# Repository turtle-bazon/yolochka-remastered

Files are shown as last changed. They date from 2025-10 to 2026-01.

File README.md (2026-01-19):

# Yolochka Remastered

Yolochka Remastered is a 36 keys (3x5 + 3 thumbs per hand) row staggered keyboard, inspired by [Aroum's YOLOCHKA](https://github.com/aroum/yolochka). It started as an attempt to turn the original YOLOCHKA into a PCB-based design.

## Images

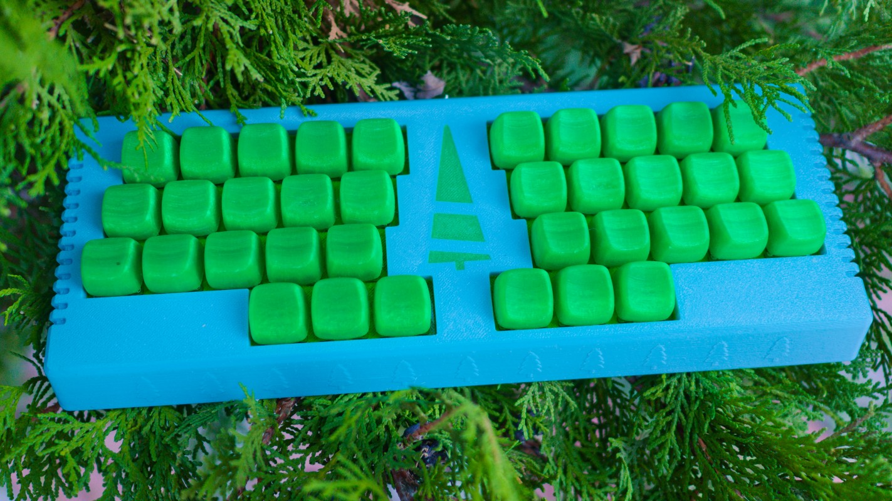
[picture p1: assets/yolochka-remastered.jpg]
yolochka-remastered


## PCB Images

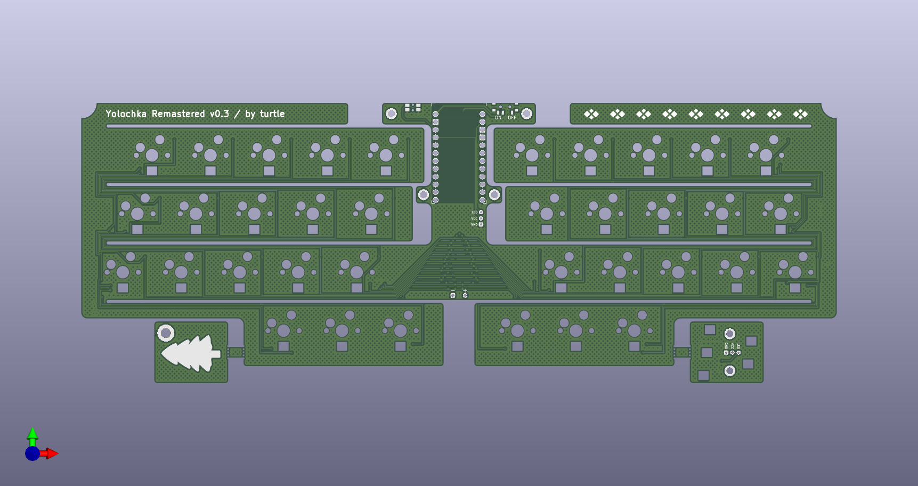
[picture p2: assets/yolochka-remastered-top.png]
yolochka-remastered-top


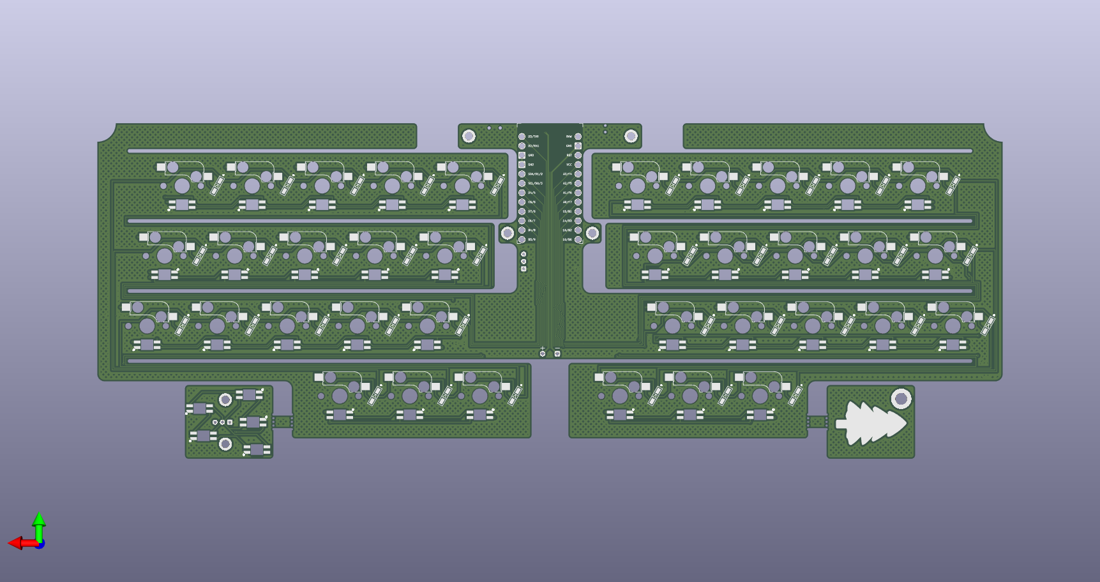
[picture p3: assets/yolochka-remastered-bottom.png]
yolochka-remastered-bottom


## Bill Of Materials

| Item | Quantity | Remarks |
| ---|---| ---|
| NRFproMicro | 1 | [Link](https://aliexpress.com/item/1005007088422530.html) |
| MX Style Mechanical Switch | 36 | Any green themed colors, but works any, see below |
| MX HotSwap Socket | 36 | Any MX Compatible, but green preferred |
| SMD Diode 1n4148 SOD123 | 36 | If you can find green or red is good |
| SK6812MINI-E | 41 | |
| MSK12C02 | 1 | Power switch |
| EVQP7C01K | 1 | Reset switch |
| 14500 li-ion battery | 2 | |
| 24 AWG wire | | Or something similar |
| M2 threaded insert | 11 | 3mm, OD 3.2mm |
| M2x4 Countersunk head | 2 | For led panel |
| M2x10 Countersunk head | 4 | For PCB |
| M2x5 Countersunk head | 7 | For Case |

## Firmware

My zmk repo is available [here](https://github.com/turtle-bazon/zmk-yolochka-remastered)

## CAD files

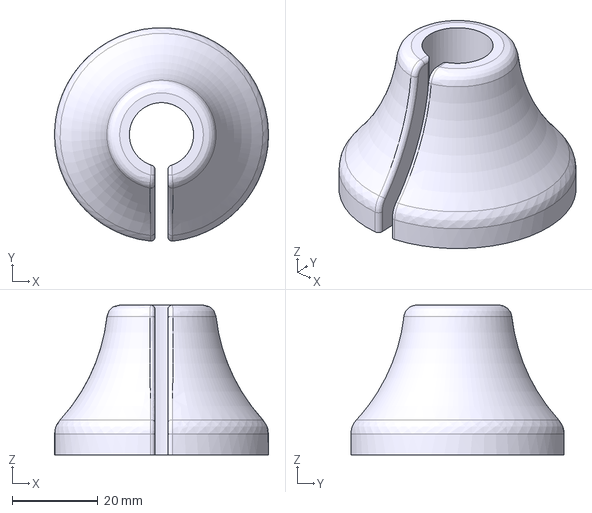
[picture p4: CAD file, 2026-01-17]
case/export/helpers/yolochka-remastered-14500-solder-helper.step
50.0 x 49.8 x 35.0 mm

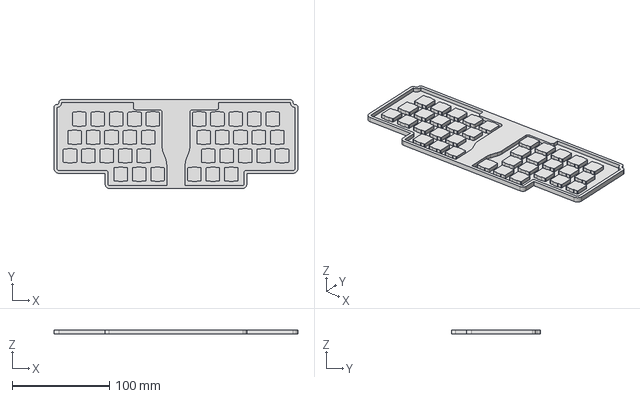
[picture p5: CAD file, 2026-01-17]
case/export/silicone-molds/yolochka-remastered-switchplate-below1.4mm-mold.step
251.5 x 91.5 x 4.60 mm

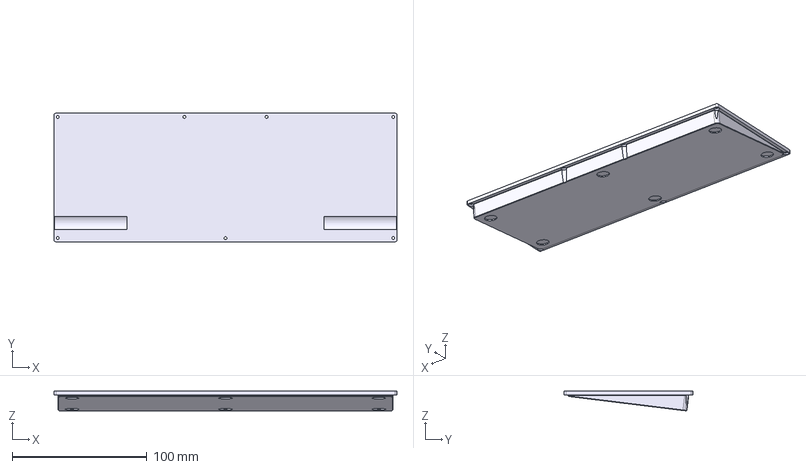
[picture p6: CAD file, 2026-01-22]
case/export/yolochka-remastered-bottom-tented.step
254.5 x 95.5 x 14.7 mm

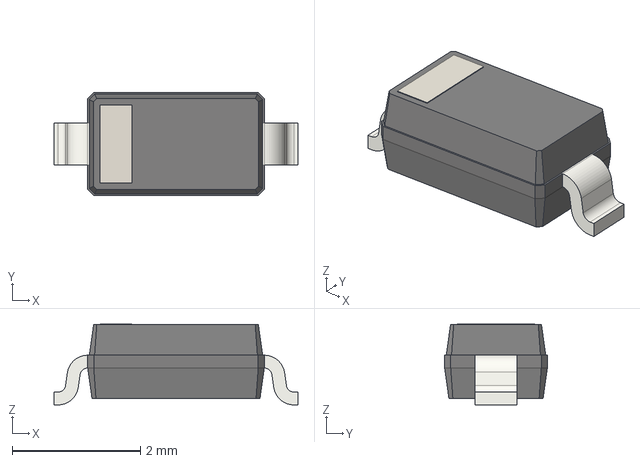
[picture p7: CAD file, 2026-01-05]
pcb/yolochka_lib/3d/D_SOD-123.step
3.80 x 1.60 x 1.26 mm

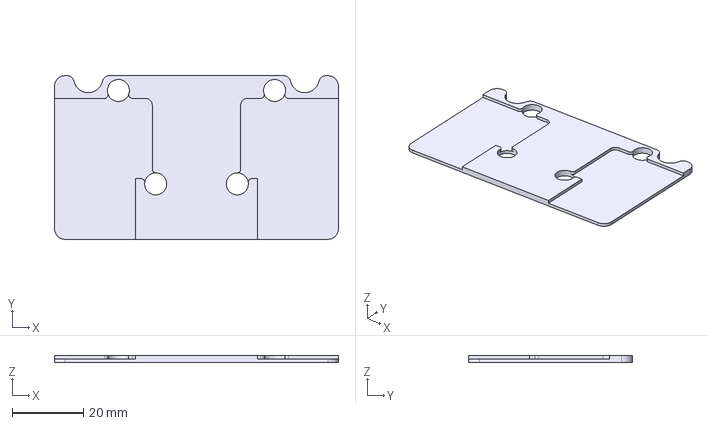
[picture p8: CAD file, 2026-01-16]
case/export/helpers/yolochka-remastered-thread-inserts-helper.step
80.0 x 46.1 x 2.00 mm

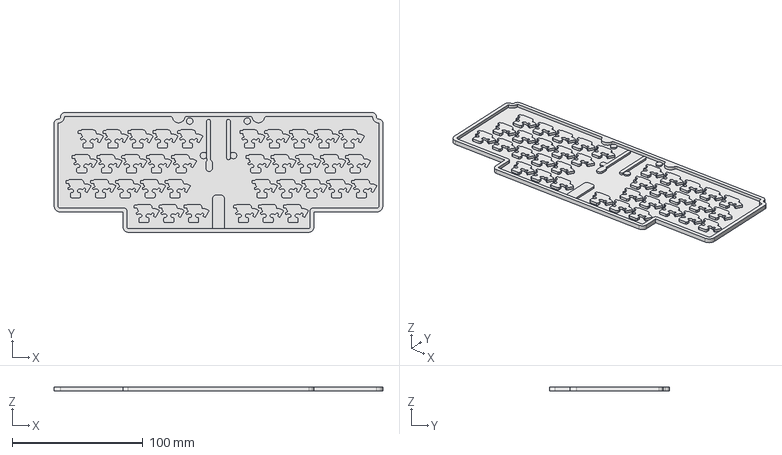
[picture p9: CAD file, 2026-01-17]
case/export/silicone-molds/yolochka-remastered-bottom-fill-mold.step
251.5 x 91.5 x 3.40 mm

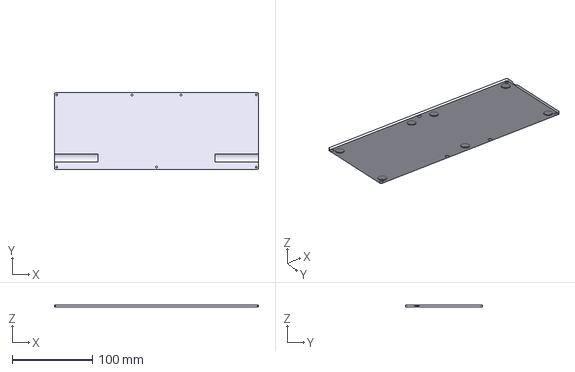
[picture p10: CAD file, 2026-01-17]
case/export/yolochka-remastered-bottom.step
254.5 x 95.5 x 3.00 mm

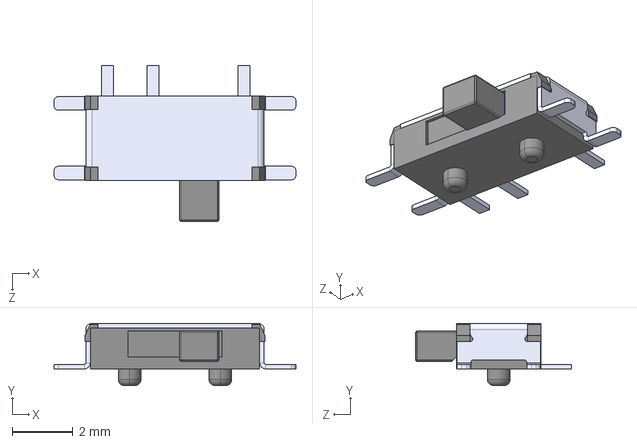
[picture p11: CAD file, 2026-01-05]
pcb/yolochka_lib/3d/MSK12C02.step
8.00 x 2.05 x 5.15 mm

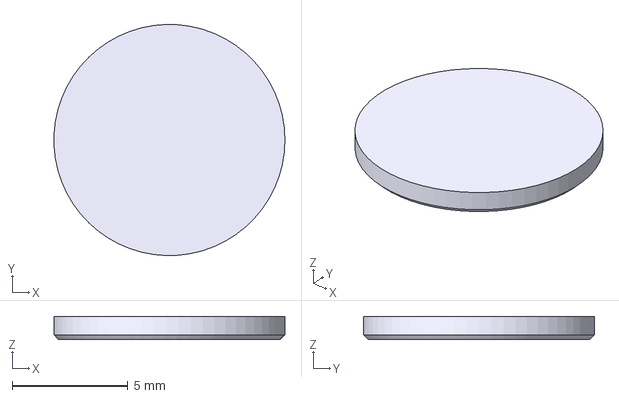
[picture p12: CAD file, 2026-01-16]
case/export/helpers/yolochka-remastered-10mmbumponsupport.step
9.99 x 10.00 x 1.00 mm

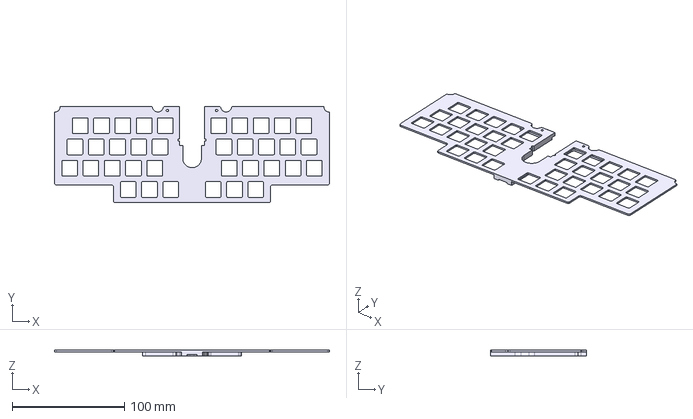
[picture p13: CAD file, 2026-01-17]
case/export/yolochka-remastered-switchplate-1.4mm.step
245.5 x 85.5 x 5.00 mm

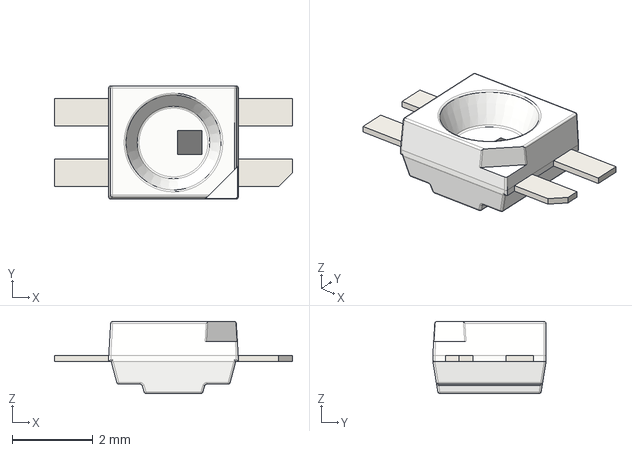
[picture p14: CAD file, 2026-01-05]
pcb/yolochka_lib/3d/LED_SK6812MINI-E.step
5.88 x 2.80 x 1.78 mm

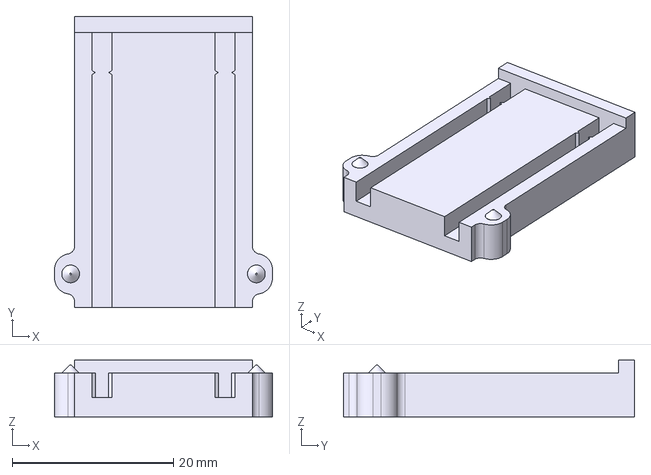
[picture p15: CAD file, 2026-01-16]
case/export/helpers/yolochka-remastered-mcu-headers-soldering-helper.step
27.0 x 36.1 x 7.00 mm

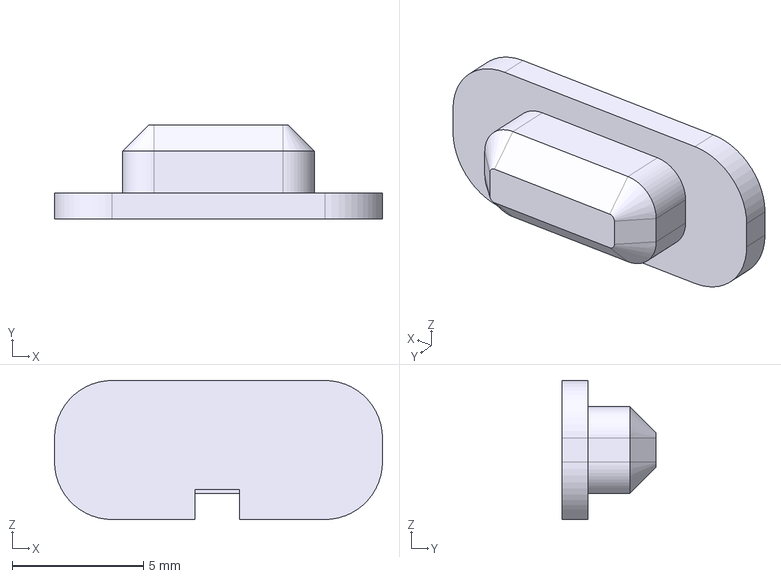
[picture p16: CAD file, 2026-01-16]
case/export/yolochka-remastered-power-switch-pusher.step
12.5 x 3.60 x 5.30 mm

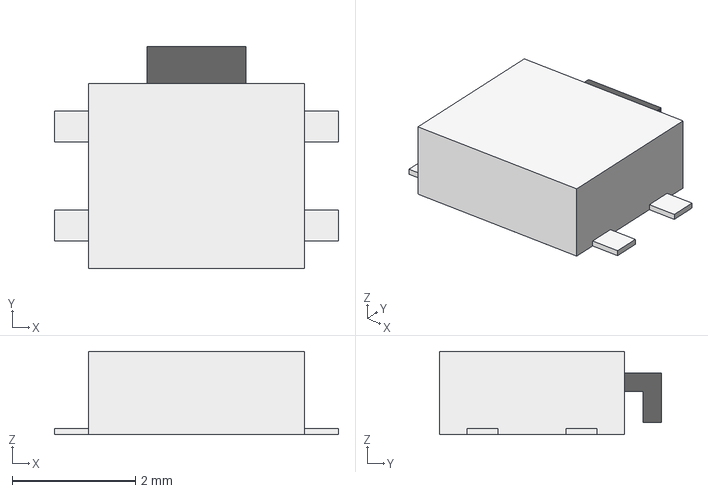
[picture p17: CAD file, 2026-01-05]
pcb/yolochka_lib/3d/turtle-tactile-switch-3x4-body.step
4.60 x 3.60 x 1.35 mm
metal-part
plastic-part

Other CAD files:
case/export/yolochka-remastered-bumpon.step
pcb/yolochka_lib/3d/SuperMini_FlatConnector.step
case/export/yolochka-remastered-top.step
pcb/yolochka_lib/3d/HotswapMX.stp
case/export/yolochka-remastered-bottom-fill.step
case/export/yolochka-remastered-reset-button-pusher.step
case/export/yolochka-remastered-switchplate.step
case/export/yolochka-remastered-top-fill.step

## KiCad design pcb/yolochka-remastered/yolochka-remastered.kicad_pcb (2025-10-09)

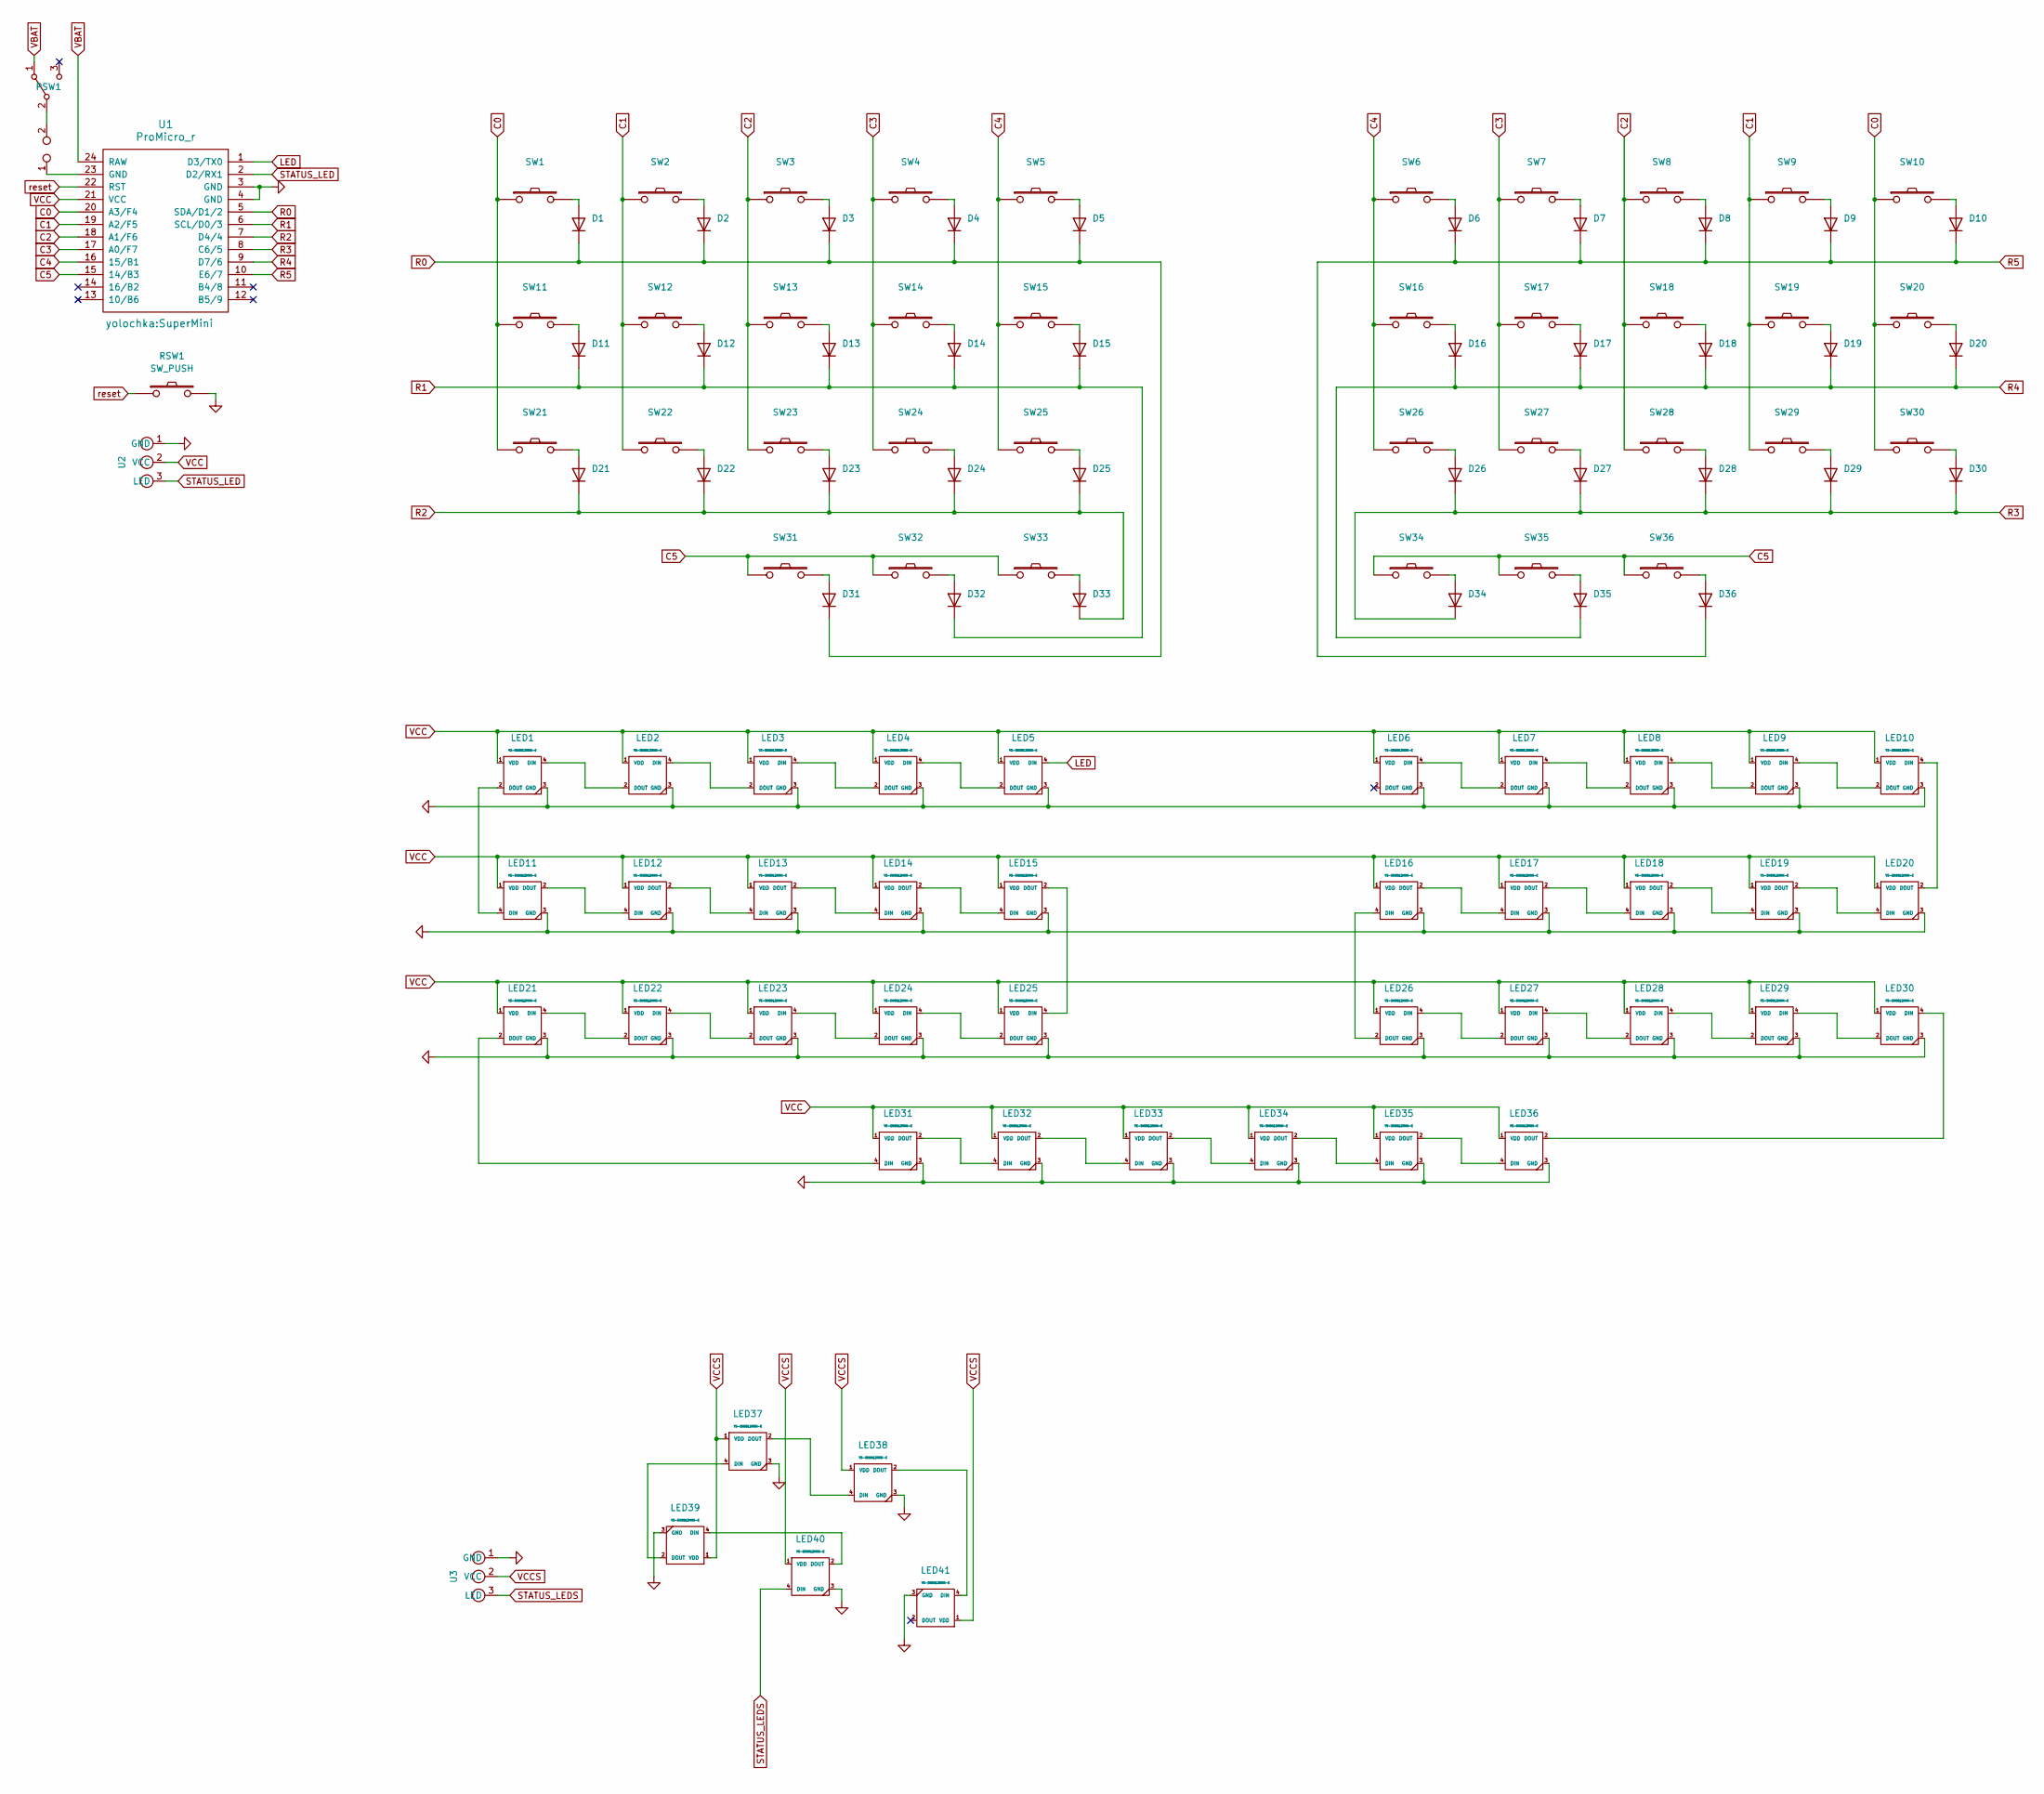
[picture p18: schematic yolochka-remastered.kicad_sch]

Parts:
D1, D2, D3, D4, D5, D6, D7, D8, D9, D10, D11, D12, D13, D14, D15, D16, D17, D18, D19, D20, D21, D22, D23, D24, D25, D26, D27, D28, D29, D30, D31, D32, D33, D34, D35, D36: 1N4148; D3_SMD_single
LED1, LED2, LED3, LED4, LED5, LED6, LED7, LED8, LED9, LED10, LED11, LED12, LED13, LED14, LED15, LED16, LED17, LED18, LED19, LED20, LED21, LED22, LED23, LED24, LED25, LED26, LED27, LED28, LED29, LED30, LED31, LED32, LED33, LED34, LED35, LED36, LED37, LED38, LED39, LED40, LED41: YS-SK6812MINI-E; YS-SK6812MINI-E_single
PSW1: SW_SPDT; MSK-12C02
RSW1: SW_PUSH; SW_EVQP7C01K
SW1, SW2, SW3, SW4, SW5, SW6, SW7, SW8, SW9, SW10, SW11, SW12, SW13, SW14, SW15, SW16, SW17, SW18, SW19, SW20, SW21, SW22, SW23, SW24, SW25, SW26, SW27, SW28, SW29, SW30, SW31, SW32, SW33, SW34, SW35, SW36: SW_PUSH; MX-single
TP1: TestPoint_2Pole; battery_conn_duplex
U1: ProMicro_r; SuperMini
U2, U3: rgb3pin

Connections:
C0: SW1.1, SW10.1, SW11.1, SW20.1, SW21.1, SW30.1, U1.20 (A3/F4)
C1: SW2.1, SW9.1, SW12.1, SW19.1, SW22.1, SW29.1, U1.19 (A2/F5)
C2: SW3.1, SW8.1, SW13.1, SW18.1, SW23.1, SW28.1, U1.18 (A1/F6)
C3: SW4.1, SW7.1, SW14.1, SW17.1, SW24.1, SW27.1, U1.17 (A0/F7)
C4: SW5.1, SW6.1, SW15.1, SW16.1, SW25.1, SW26.1, U1.16 (15/B1)
C5: SW31.1, SW32.1, SW33.1, SW34.1, SW35.1, SW36.1, U1.15 (14/B3)
GND: LED1.3 (GND), LED2.3 (GND), LED3.3 (GND), LED4.3 (GND), LED5.3 (GND), LED6.3 (GND), LED7.3 (GND), LED8.3 (GND), LED9.3 (GND), LED10.3 (GND), LED11.3 (GND), LED12.3 (GND), LED13.3 (GND), LED14.3 (GND), LED15.3 (GND), LED16.3 (GND), LED17.3 (GND), LED18.3 (GND), LED19.3 (GND), LED20.3 (GND), LED21.3 (GND), LED22.3 (GND), LED23.3 (GND), LED24.3 (GND), LED25.3 (GND), LED26.3 (GND), LED27.3 (GND), LED28.3 (GND), LED29.3 (GND), LED30.3 (GND), LED31.3 (GND), LED32.3 (GND), LED33.3 (GND), LED34.3 (GND), LED35.3 (GND), LED36.3 (GND), RSW1.2, U1.3 (GND), U1.4 (GND), U2.1 (GND)
GNDS: LED37.3 (GND), LED38.3 (GND), LED39.3 (GND), LED40.3 (GND), LED41.3 (GND), U3.1 (GND)
LED: LED5.4 (DIN), U1.1 (D3/TX0)
unnamed: D1.2 (A), SW1.2
unnamed: D2.2 (A), SW2.2
unnamed: D3.2 (A), SW3.2
unnamed: D4.2 (A), SW4.2
unnamed: D5.2 (A), SW5.2
unnamed: D6.2 (A), SW6.2
unnamed: D7.2 (A), SW7.2
unnamed: D8.2 (A), SW8.2
unnamed: D9.2 (A), SW9.2
unnamed: D10.2 (A), SW10.2
unnamed: D11.2 (A), SW11.2
unnamed: D12.2 (A), SW12.2
unnamed: D13.2 (A), SW13.2
unnamed: D14.2 (A), SW14.2
unnamed: D15.2 (A), SW15.2
unnamed: D16.2 (A), SW16.2
unnamed: D17.2 (A), SW17.2
unnamed: D18.2 (A), SW18.2
unnamed: D19.2 (A), SW19.2
unnamed: D20.2 (A), SW20.2
unnamed: D21.2 (A), SW21.2
unnamed: D22.2 (A), SW22.2
unnamed: D23.2 (A), SW23.2
unnamed: D24.2 (A), SW24.2
unnamed: D25.2 (A), SW25.2
unnamed: D26.2 (A), SW26.2
unnamed: D27.2 (A), SW27.2
unnamed: D28.2 (A), SW28.2
unnamed: D29.2 (A), SW29.2
unnamed: D30.2 (A), SW30.2
unnamed: D31.2 (A), SW31.2
unnamed: D32.2 (A), SW32.2
unnamed: D33.2 (A), SW33.2
unnamed: D34.2 (A), SW34.2
unnamed: D35.2 (A), SW35.2
unnamed: D36.2 (A), SW36.2
unnamed: LED1.4 (DIN), LED2.2 (DOUT)
unnamed: LED1.2 (DOUT), LED11.4 (DIN)
unnamed: LED2.4 (DIN), LED3.2 (DOUT)
unnamed: LED3.4 (DIN), LED4.2 (DOUT)
unnamed: LED4.4 (DIN), LED5.2 (DOUT)
unnamed: LED6.4 (DIN), LED7.2 (DOUT)
unnamed: LED7.4 (DIN), LED8.2 (DOUT)
unnamed: LED8.4 (DIN), LED9.2 (DOUT)
unnamed: LED10.4 (DIN), LED20.2 (DOUT)
unnamed: LED9.4 (DIN), LED10.2 (DOUT)
unnamed: LED11.2 (DOUT), LED12.4 (DIN)
unnamed: LED12.2 (DOUT), LED13.4 (DIN)
unnamed: LED13.2 (DOUT), LED14.4 (DIN)
unnamed: LED14.2 (DOUT), LED15.4 (DIN)
unnamed: LED15.2 (DOUT), LED25.4 (DIN)
unnamed: LED16.4 (DIN), LED26.2 (DOUT)
unnamed: LED16.2 (DOUT), LED17.4 (DIN)
unnamed: LED17.2 (DOUT), LED18.4 (DIN)
unnamed: LED18.2 (DOUT), LED19.4 (DIN)
unnamed: LED19.2 (DOUT), LED20.4 (DIN)
unnamed: LED21.4 (DIN), LED22.2 (DOUT)
unnamed: LED21.2 (DOUT), LED31.4 (DIN)
unnamed: LED22.4 (DIN), LED23.2 (DOUT)
unnamed: LED23.4 (DIN), LED24.2 (DOUT)
unnamed: LED24.4 (DIN), LED25.2 (DOUT)
unnamed: LED26.4 (DIN), LED27.2 (DOUT)
unnamed: LED27.4 (DIN), LED28.2 (DOUT)
unnamed: LED28.4 (DIN), LED29.2 (DOUT)
unnamed: LED29.4 (DIN), LED30.2 (DOUT)
unnamed: LED30.4 (DIN), LED36.2 (DOUT)
unnamed: LED31.2 (DOUT), LED32.4 (DIN)
unnamed: LED32.2 (DOUT), LED33.4 (DIN)
unnamed: LED33.2 (DOUT), LED34.4 (DIN)
unnamed: LED34.2 (DOUT), LED35.4 (DIN)
unnamed: LED35.2 (DOUT), LED36.4 (DIN)
unnamed: LED37.4 (DIN), LED39.2 (DOUT)
unnamed: LED37.2 (DOUT), LED38.4 (DIN)
unnamed: LED38.2 (DOUT), LED41.4 (DIN)
unnamed: LED39.4 (DIN), LED40.2 (DOUT)
unnamed: PSW1.2 (B), TP1.2
unnamed: TP1.1, U1.23 (GND)
R0: D1.1 (K), D2.1 (K), D3.1 (K), D4.1 (K), D5.1 (K), D31.1 (K), U1.5 (SDA/D1/2)
R1: D11.1 (K), D12.1 (K), D13.1 (K), D14.1 (K), D15.1 (K), D32.1 (K), U1.6 (SCL/D0/3)
R2: D21.1 (K), D22.1 (K), D23.1 (K), D24.1 (K), D25.1 (K), D33.1 (K), U1.7 (D4/4)
R3: D26.1 (K), D27.1 (K), D28.1 (K), D29.1 (K), D30.1 (K), D34.1 (K), U1.8 (C6/5)
R4: D16.1 (K), D17.1 (K), D18.1 (K), D19.1 (K), D20.1 (K), D35.1 (K), U1.9 (D7/6)
R5: D6.1 (K), D7.1 (K), D8.1 (K), D9.1 (K), D10.1 (K), D36.1 (K), U1.10 (E6/7)
STATUS_LED: U1.2 (D2/RX1), U2.3 (LED)
STATUS_LEDS: LED40.4 (DIN), U3.3 (LED)
VBAT: PSW1.1 (A), U1.24 (RAW)
VCC: LED1.1 (VDD), LED2.1 (VDD), LED3.1 (VDD), LED4.1 (VDD), LED5.1 (VDD), LED6.1 (VDD), LED7.1 (VDD), LED8.1 (VDD), LED9.1 (VDD), LED10.1 (VDD), LED11.1 (VDD), LED12.1 (VDD), LED13.1 (VDD), LED14.1 (VDD), LED15.1 (VDD), LED16.1 (VDD), LED17.1 (VDD), LED18.1 (VDD), LED19.1 (VDD), LED20.1 (VDD), LED21.1 (VDD), LED22.1 (VDD), LED23.1 (VDD), LED24.1 (VDD), LED25.1 (VDD), LED26.1 (VDD), LED27.1 (VDD), LED28.1 (VDD), LED29.1 (VDD), LED30.1 (VDD), LED31.1 (VDD), LED32.1 (VDD), LED33.1 (VDD), LED34.1 (VDD), LED35.1 (VDD), LED36.1 (VDD), U1.21 (VCC), U2.2 (VCC)
VCCS: LED37.1 (VDD), LED38.1 (VDD), LED39.1 (VDD), LED40.1 (VDD), LED41.1 (VDD), U3.2 (VCC)
reset: RSW1.1, U1.22 (RST)

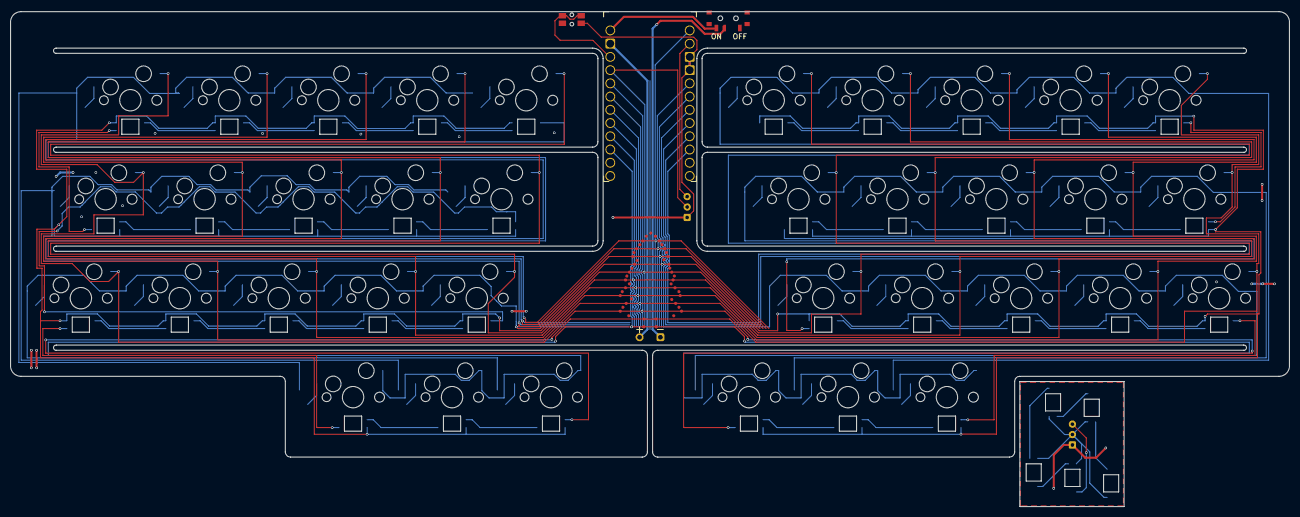
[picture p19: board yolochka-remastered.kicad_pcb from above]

Board: 2 copper layers, 245.5 x 85.5 mm, 119 parts (0 on the bottom side), 98 nets.

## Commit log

2025-07-22 Initial routing
    [yolochka-remastered.kicad_pcb, yolochka-remastered.kicad_sch]
2025-08-02 Change led position and initial reroute
    [yolochka-remastered.kicad_pcb]
2025-09-23 Initial route
    [yolochka-remastered.kicad_pcb, yolochka-remastered.kicad_sch]
2025-09-29 Mostly routed
    [yolochka-remastered.kicad_pcb]
2025-09-29 Switches routed, rgb led almost
    [yolochka-remastered.kicad_pcb]
2025-09-30 Elements added, alsmost full routed
    [yolochka-remastered.kicad_pcb, yolochka-remastered.kicad_sch]
2025-10-09 All things routed
    [yolochka-remastered.kicad_pcb, yolochka-remastered.kicad_sch]
2025-10-10 PCB prepared
2025-10-15 Version 0.2 with cuts for mount colons
2026-01-05 Additional materials
    [D_SOD-123.step, HotswapMX.stp, LED_SK6812MINI-E.step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]
2026-01-16 Case source and exports
    [yolochka-remastered-10mmbumponsupport.step, yolochka-remastered-bottom-fill.step, yolochka-remastered-bottom.step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]
2026-01-17 Added silicone molds and some helpers
    [yolochka-remastered-14500-solder-helper.step, yolochka-remastered-bottom-fill-mold.step, yolochka-remastered-switchplate-1.4mm.step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]
2026-01-17 Fix battery pads
2026-01-17 Slightly increased tolerances for battery cuts in bottom
    [yolochka-remastered-bottom.step]
2026-01-17 Slightly increased tolerances for battery cuts in bottom (source files)
2026-01-19 Fixes of screw heads
2026-01-22 Added tented bottom
    [yolochka-remastered-bottom-tented.step]

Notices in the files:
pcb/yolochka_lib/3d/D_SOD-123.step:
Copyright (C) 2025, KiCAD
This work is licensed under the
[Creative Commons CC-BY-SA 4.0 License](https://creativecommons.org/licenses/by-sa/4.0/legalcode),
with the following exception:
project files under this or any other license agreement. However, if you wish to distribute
